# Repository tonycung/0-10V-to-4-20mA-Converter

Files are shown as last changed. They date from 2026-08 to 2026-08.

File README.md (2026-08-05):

# 0-10V-to-4-20mA-Converter
A simple 0–10 V to 4–20 mA analog signal converter designed with KiCad.

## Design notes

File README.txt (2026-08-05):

# 0–10 V to 4–20 mA Converter

A simple analog voltage-to-current converter designed with KiCad.

## Project Objective

Design a PCB that converts a 0–10 V input signal into a proportional 4–20 mA output.

## Target

| Vin | Iout |
|---:|---:|
| 0 V | 4 mA |
| 2.5 V | 8 mA |
| 5 V | 12 mA |
| 7.5 V | 16 mA |
| 10 V | 20 mA |

## Tools

- KiCad
- LTspice
- Git / GitHub

## Status

Project initialization.

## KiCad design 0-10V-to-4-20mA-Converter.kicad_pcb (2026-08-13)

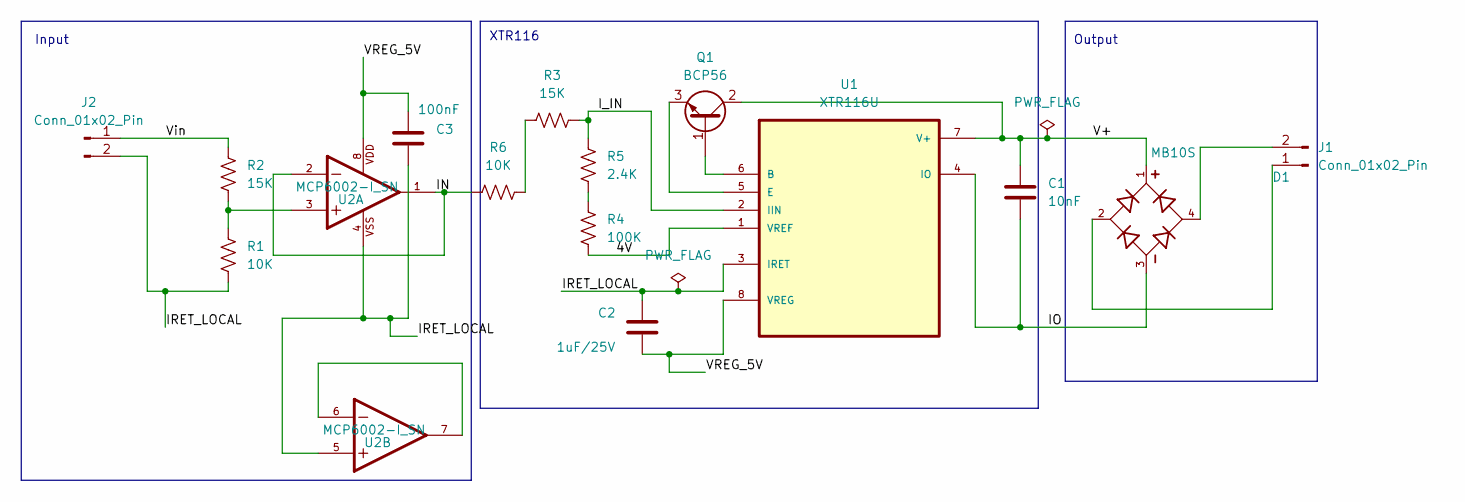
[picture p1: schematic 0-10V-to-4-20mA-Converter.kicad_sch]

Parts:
C1: 10nF; C_0805_2012Metric_Pad1.18x1.45mm_HandSolder
C2: 1uF/25V; C_0805_2012Metric_Pad1.18x1.45mm_HandSolder
C3: 100nF; C_0805_2012Metric_Pad1.18x1.45mm_HandSolder
D1: MB10S; MB10S_DiodesInc
J1, J2: Conn_01x02_Pin; KF301-2P_Universal_P5.08
Q1: BCP56; SOT-223-3_TabPin2
R1, R6: 10K; R_0805_2012Metric_Pad1.20x1.40mm_HandSolder
R2, R3: 15K; R_0805_2012Metric_Pad1.20x1.40mm_HandSolder
R4: 100K; R_0805_2012Metric_Pad1.20x1.40mm_HandSolder
R5: 2.4K; R_0805_2012Metric_Pad1.20x1.40mm_HandSolder
U1: XTR116U; SOIC-8_3.9x4.9mm_P1.27mm
U2: MCP6002-I_SN; SOIC-8_3.9x4.9mm_P1.27mm; PARTREV L

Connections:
/4V: R4.2, U1.1 (VREF)
/IN: R6.1, U2.1, U2.2
/IO: C1.2, D1.3, U1.4 (IO)
/IRET_LOCAL: C2.1, C3.2, J2.2, R1.2, U1.3 (IRET), U2.4, U2.5
/I_IN: R3.2, R5.1, U1.2 (IIN)
/V+: C1.1, D1.1, Q1.2 (C), U1.7 (V+)
/VREG_5V: C2.2, C3.1, U1.8 (VREG), U2.8
/Vin: J2.1, R2.1
unnamed: D1.2, J1.1
unnamed: D1.4, J1.2
unnamed: Q1.1 (B), U1.6 (B)
unnamed: Q1.3 (E), U1.5 (E)
unnamed: R1.1, R2.2, U2.3
unnamed: R3.1, R6.2
unnamed: R4.1, R5.2
unnamed: U2.6, U2.7

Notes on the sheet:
XTR116
Output
Input

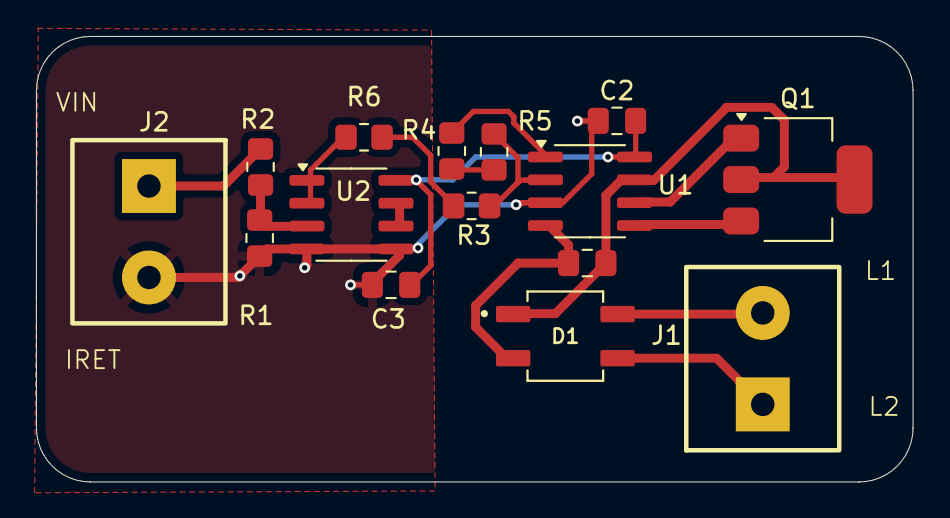
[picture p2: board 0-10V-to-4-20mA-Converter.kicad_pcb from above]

Board: 2 copper layers, 48.7 x 24.8 mm, 15 parts (0 on the bottom side), 16 nets.

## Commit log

2026-08-05 initial project setup
    [0-10V-to-4-20mA-Converter.kicad_pcb, 0-10V-to-4-20mA-Converter.kicad_sch]
2026-08-05 ERC and Schematic completed
    [0-10V-to-4-20mA-Converter.kicad_sch]
2026-08-06 XTR116 and MCP6002
    [0-10V-to-4-20mA-Converter.kicad_sch]
2026-08-06 BP56-16 changed
    [0-10V-to-4-20mA-Converter.kicad_sch]
2026-08-11 Complete XTR116 PCB layout_DRC clean
    [0-10V-to-4-20mA-Converter.kicad_pcb, 0-10V-to-4-20mA-Converter.kicad_sch]
2026-08-13 completed Ver1
    [0-10V-to-4-20mA-Converter-B_Cu.gbr, 0-10V-to-4-20mA-Converter-B_Mask.gbr, 0-10V-to-4-20mA-Converter-Edge_Cuts.gbr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]
